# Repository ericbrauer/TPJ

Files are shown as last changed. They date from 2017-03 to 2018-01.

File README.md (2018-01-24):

# TPJ
Final Project for ECT @ Seneca. "Project Skylight"

# PROJECT SKYLIGHT
Eric Brauer 

## Executive Summary
Project Skylight is an Internet-connected light that simulates daylight cycles. It’s meant for
use in places where there are no external windows, and it can be used to get a quick visual
reference for the time of day. Project skylight is composed of a small microcontroller with wifi
capabilities, and 16 RGB LEDs. The device is meant to run with very little set-up, but a
web-based user interface can be used for further configuration. In the report, the operation
and specifications of Project Skylight are covered in more detail.

## Functional Features
The product requirements, as envisioned, are as follows:
- Project Skylight (PS) asks for WiFi credentials, and connects to a WiFi router.
- PS serves a webpage which is used to configure the device and to provide the user’s
city of residence.
- PS uses the OpenWeatherMap API to get the time of dawn and dusk. The device
also uses an NTP server to synchronise the current time.
- PS changes the colour and brightness of LEDs based on current time in reference to
sunrise and sunset times.
- PS monitors a potentiometer, which will be used to dim or turn off the LED light.
- Further configuration is possible from the web interface. This includes setting manual
daylight times.

## Product Specifications
- Powered from micro USB port
- Operates at nominal indoor temperatures, not for outdoor use
- Luminosity of around 200 - 400 Lumens
- WiFi range 20m
- Current consumption no higher than 1.5A

## Theory of Operation
### Power Concerns
The ESP-12f requires a typical voltage of 3.3 Volts. The Neopixel array require a voltage of 4
to 7 Volts. Thus a voltage regulation stage is required. USB provides 5 Volts, and this power
is used for the Neopixels. Power for the ESP-12f is supplied by an LD1117.

Power consumption is based heavily on several factors: transmission and reception by the
WiFi module on the ESP-12f, signal strength of the same, and brightness levels of the
Neopixels. If a single Neopixel is set to white with maximum brightness, then each of its
three RGB LEDs requires 20 mA. There is never a situation when the Skylight is generating
this state, however. Full brightness of the daytime SkyState would represent the maximum
current consumption.

4 LEDs displaying white = 60mA * 4 240mA

12 LEDs displaying cyan = 40mA * 12 480mA

Total Current for Neopixels: **720mA**

In addition, the ESP-12f requires a maximum of 100mA. Meaning that a USB adapter rated
at 1A should be sufficient for proper function and also provide a buffer of almost 20%.

### Initial State / Connectivity
The ESP-12f is a popular IC among the maker community, and much work has been done to
implement a thorough Arduino library which exposes much of the connectivity capability of
the chip. The Skylight in particular makes use of several libraries to implement the initial
Access Point state (used to enter WiFi credentials), to communicate to OpenWeatherMap,
and to serve a web-based user interface.

**ESP8266WiFi** exposes functions for connecting to a WiFi access point and communicating
over TCP/IP.

**ESP8266WebServer** allows to ESP to also act as a web server, and serve HTTP code to
clients.

**ESP8266mDNS** provides a ‘micro DNS’ server which will associate a URL with whatever IP
address is assigned to the ESP’s web server.

**WifiManager** checks flash for a WiFi SSID and password that was previously used to
connect. If these don’t exist, WifiManager will set the ESP-12 to station mode with an SSID
set in software. The user can connect to this access point, and then navigate to the url
specified by the micro-DNS server. From this webpage, the user has the option to scan for
available access points, and then enter a password to connect to this access point. From
this point, the ESP exits station mode and attempts to connect to the access point as a
client. If it is successful, these credentials will be saved in flash memory to be used on
startup.

### The Web Interface
The ESP handles web requests directed at the url created by the micro DNS server. On the
Skylight, the url is skylight.local. The main interface is located at the root. Other webpages
are used to acknowledge user requests, and exist at /submit, /demo and /reset. All other
requests will result in a HTTP code of 404.
A typical user request is to manually change the time at which a sunset event occurs. The
time desired is typed into text boxes, and the ‘save’ button is pressed. Information inside the
text boxes is saved as arguments. The arguments are validated first. The arguments are
checked to ensure that they are numerical and in a proper 12-hour time format. A bad
request will result in a ‘bad request’ message and a link back to the root page. A good
request will be accepted. Finally, the browser will navigate to skylight.local/submit, where the
user is notified that the alarm has been set.

### Adafruit NeoPixel Array
Neopixels are addressable RGB LEDs. Control circuitry, LEDs, and internal oscillators are all
included in one package. Data can be received from a microcontroller at speeds of 800kbps,
and outputted to the next neopixel. This allows an array of neopixels to be controlled from
one data pin.
Each neopixel requires 24bits of information. The first neopixel uses 24 bits to set the values
of discrete red, green and blue LEDs. Each of these LEDs takes a PWM 8-bit signal to set its
intensity, resulting in 255 possible states. Once the state of neopixel has been set,
subsequent data is amplified and sent through a ‘Data Out’ line to program the next
neopixel. The advantage of neopixels is their flexibility, but larger arrays will require far more
memory and processing than some microcontrollers can provide. Since the Skylight uses
only 16 neopixels, performance requirements are relatively light.9
Adafruit provides an Arduino Library for communicating with the Neopixel array. The
Neopixels are powered from a 5V VCC line and the data line is connected to the ESP’s
GPIO pin 14.
### Brightness Control
A potentiometer is connected to the ESP-12’s single Analog-to-Digital converter. A standard
Arduino library function is used to convert this number to a 10-bit value, which is then to an
8-bit value using bit shift. The 8-bit value is used as an argument for the setBrightness
function which is part of the Adafruit Neopixel library. Using the ADC with interrupts proved
to be problematic, and so the ADC is polled in loop() and if its value changes, the
setBrightness function is called. The potentiometer is connected to the ADC pin identified as
0.
### Setting dusk_time and dawn_time From OpenWeatherMap.org
OpenWeatherMap provides an API that can be used for free with registration for a smaller
number of requests. For the Skylight prototype, this is sufficient. Documentation for the API
is located at  [OpenWeatherMap](http://openweathermap.org/current). The API can be used with several different
formats of location data; for simplicity’s sake a GET request is used encoded with the city
and country code are used along with an API key.
The HTTP response is in a JSON format. First, the HTTP header of the response is
discarded. Then ArduinoJson library is used to parse the response. Most information is
related to weather conditions and is not used. The sunrise and sunset times are sent in
epoch time based on UTC. In order to set this to local time, a timezone offset is added to
these times and the result is stored in memory.
### Using NTP to Sync Local Time
NTPClient is another library used to communicate with NTP servers. This is used with
TimeLib to set the ESP’s time. A timezone offset is required by the library.
### State Machine
Assuming that NTP and GET Requests have succeeded, the Skylight will compare current
time with the next scheduled event. Once current time is within forty minutes of a sunrise or
sunset, the Skylight enters a DUSK or DAWN event. Both events are identical, but DUSK
occurs in reverse order.
There are three parts to a transition, and each takes 20 minutes. Two of the parts of the
transition occur before the event time, and one occurs after. Each part of the transition is
handled by a function, and each function takes as an argument an 8-bit number.

`SkyState1(0-255) SkyState2(0-255) SkyState3(0-255)`

Duration: 1200 seconds Duration: 1200 seconds Duration: 1200 seconds
In the case of DAWN, the actual sunrise_time is the time between SkyState2 and SkyState3.
In order to set the argument for each SkyState function, a simple equation derived from the
Radiometric Equation is used.

`y = (x - 2400) / (-3600 / 765)`

Where x is equal to seconds until event and y is equal to the skyState argument.
What this means is that approximately every 7 seconds, SkyState functions will increment
the levels of the Neopixel LEDs which results in a simulated dawn or dusk event. Once the
current time is over twenty minutes past the last event, the state machine will return to a
state where it decides if it is waiting for dawn or waiting for dusk. If both dawn and dusk
events are earlier than the current time, the state machine will attempt to request new times
from OpenWeatherMap.

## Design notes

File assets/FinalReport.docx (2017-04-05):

# Project Skylight

Project Report

Eric Brauer

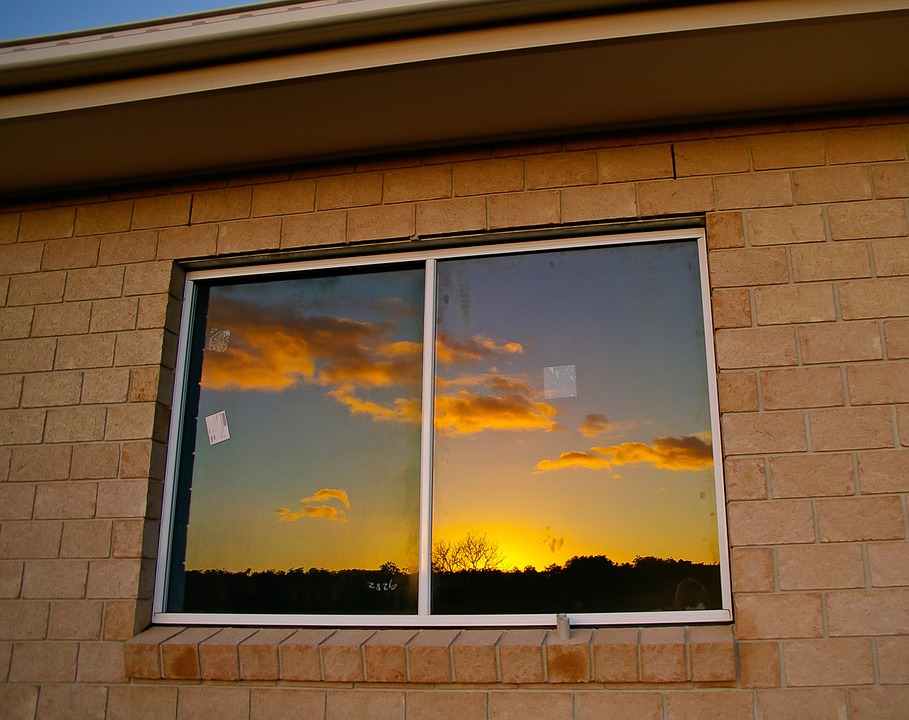
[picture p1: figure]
window reflection sky sunset ...

Subject: Technology Project - TPJ655

Program: Computer Engineering Technology

Instructor: B. Shefler, rm. A4022, ext. 26429

Date: 4/4/2017

SENECA COLLEGE OF APPLIED ARTS AND TECHNOLOGY

School of Electronics and Mechanical Engineering Technology

1750 Finch Ave East, Toronto, Ontario, M2J 2X5. Tel. 416-491-5050 Fax 416-490-9839

www.senecacollege.ca

Executive Summary 2

Introduction 3

Functional Features 3

Product Specifications 3

Operating Instructions 3

Design 4

Hardware Block Diagram 4

Software Flow Chart 5

Description of Components 6

Graphical User Interface Mockups 7

Theory of Operation 7

Maintenance Requirements 10

Conclusion 10

Further Steps 11

Appendix 12

Schematic 12

Bill Of Materials 13

Datasheets 13

Contact Information 13

On the CD: 14

## Executive Summary

Project Skylight is an Internet-connected light that simulates daylight cycles. It’s meant for use in places where there are no external windows, and it can be used to get a quick visual reference for the time of day. Project skylight is composed of a small microcontroller with wifi capabilities, and 16 RGB LEDs. The device is meant to run with very little set-up, but a web-based user interface can be used for further configuration. In the report, the operation and specifications of Project Skylight are covered in more detail.

## Introduction

In Toronto and in many densely-populated areas, people often and work in rooms without exterior windows. With no visual reference to the time of day, it can be easy to lose track of time: whether it’s daytime, evening, or night. This leads to feelings of disorientation and can exacerbate sleep disturbances.

Project skylight is meant to address this problem. The device being proposed is an Internet-connected light that simulates the time of day. The time of day is simulated with an appropriate colour and brightness of light. Daytime, nighttime, and transitional periods ie. dawn and dusk would have different characteristics which would give people the same quick visual reference that one usually gets by glancing out the window.

## Functional Features

The product requirements, as envisioned, are as follows:

- Project Skylight (PS) asks for WiFi credentials, and connects to a WiFi router.
- PS serves a webpage which is used to configure the device and to provide the user’s city of residence.
- PS uses the OpenWeatherMap API to get the time of dawn and dusk. The device also uses an NTP server to synchronise the current time.
- PS changes the colour and brightness of LEDs based on current time in reference to sunrise and sunset times.
- PS monitors a potentiometer, which will be used to dim or turn off the LED light.
- Further configuration is possible from the web interface. This includes setting manual daylight times.

## Product Specifications

- Powered from micro USB port
- Operates at nominal indoor temperatures, not for outdoor use
- Luminosity of around 200 - 400 Lumens
- WiFi range 20m
- Current consumption no higher than 1.5A

## Operating Instructions

Before proceeding, please observe the following safety instructions:

For indoor use only. Keep away from water or heat sources. Use only power adapters approved by the CSA.

Initial Setup:

- Project Skylight can be used with any micro-USB power adapter that supplies 5V. It should also be able to supply 1A. Plug the Skylight into the wall, and hang it or place it wherever you like.
- On startup, the light will flash yellow. This means that the skylight was unable to detect a wifi station in memory, and is in station mode so that wifi information can be entered.
- Use a smartphone or laptop to connect to the Access Point called ‘SKYLIGHT.’ Once connected, use the browser to go to skylight.local.
- Select your home router, and enter the password. The skylight will now attempt to connect to the internet. If it is successful, you should see it simulate the time of day. If there is a problem, the light will blink red. Please check your wifi information again, or contact customer support.

Changing brightness:

- Use the dial or adjust desired brightness. These settings will be remembered until you change them. If the skylight doesn’t seem to be responding, check first that the light hasn’t been turned off.

Changing transition times:

- If you wish to change the time at which sunrise or sunset are initiated, use a device connected to your home router. Open a browser window and go to skylight.local.
- Set a time for sunrise or sunset, and press the ‘save’ button. If the time entered is valid, the skylight will transition 30 minutes before the specified time, and the transition will be completed 30 minutes after. Manual times do not repeat. After the specified time, the skylight will revert to simulating the actual time of day.

## Design

### Hardware Block Diagram

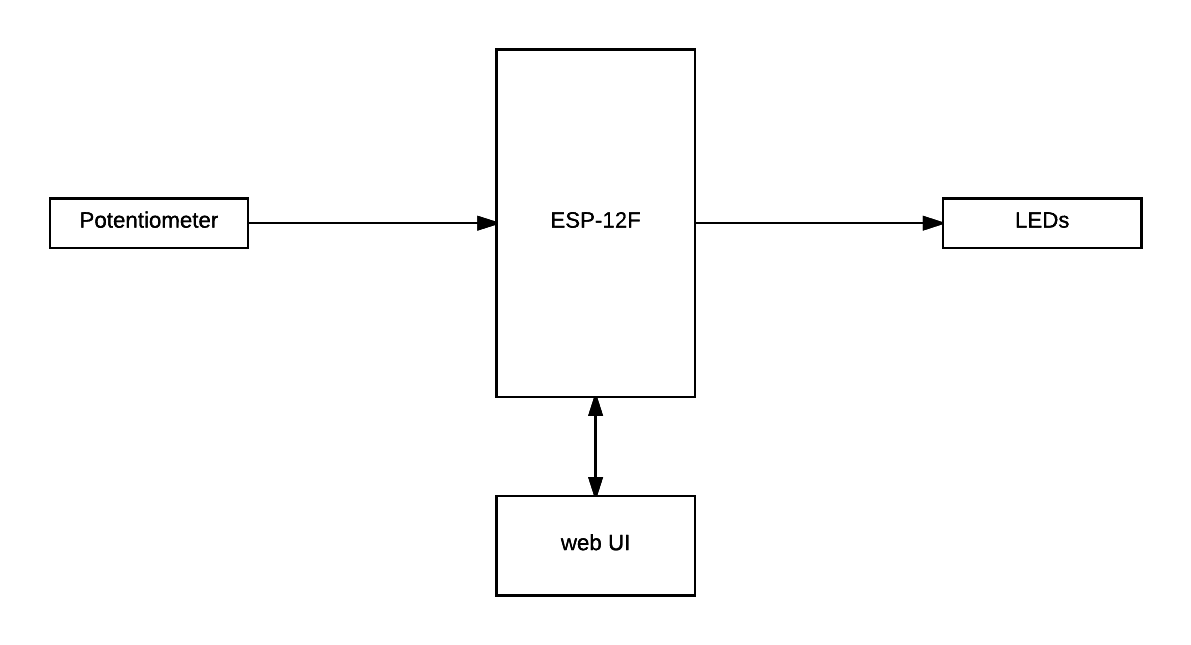
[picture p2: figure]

### Software Flow Chart

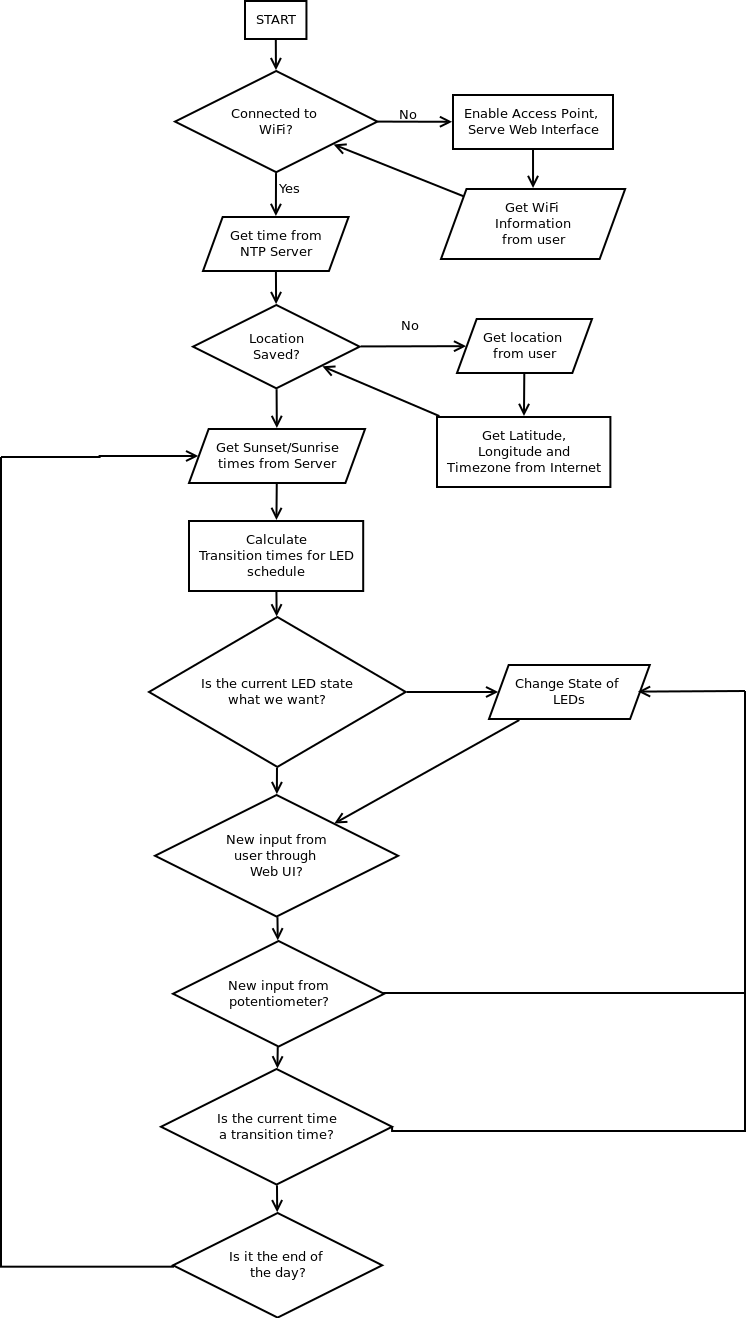
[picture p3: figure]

### Description of Components

# | Component Name | Specifications

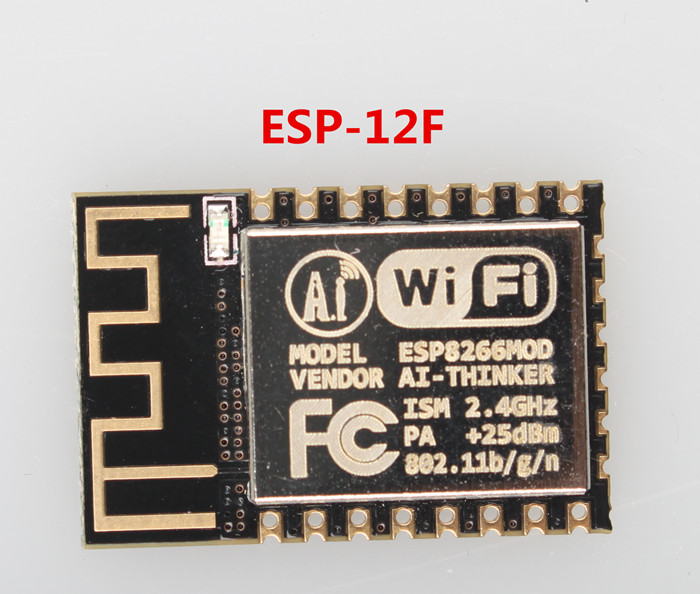
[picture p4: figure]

1 | Espressif ESP-12f | - Operating Voltage: 3.0~3.6V - Operating Current Average value: 80mA - SDIO 2.0, (H) SPI, UART, I2C, I2S, IRDA, PWM, GPIO - 802.11 b/g/n - Integrated low power 32-bit MCU, 80 MHz clock speed - 36 kB RAM, 2 MB flash

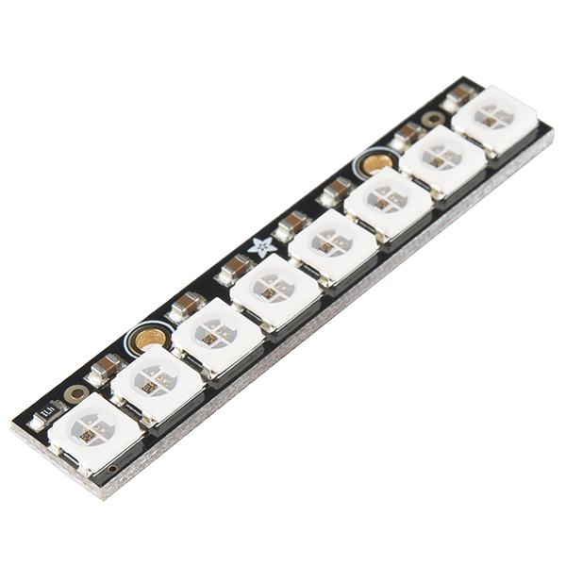
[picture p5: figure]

2 | Adafruit Neopixel Strip | - Provides 8 WS2812b Addressable RGB LEDs - Voltage VCC: +6.0~+7.0V - Operating current: 60mA - 256 brightness levels per colour

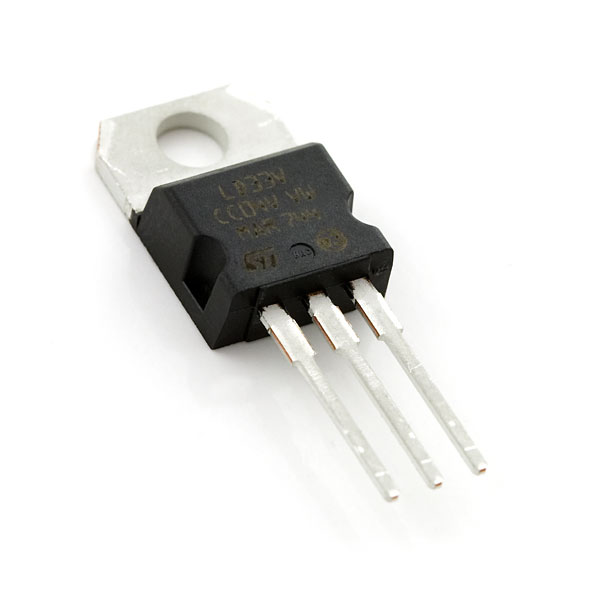
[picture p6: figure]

3 | LD1117V33 Voltage Regulator | - Output Voltage: 3.3V - Output Current: 800mA - Dropout Voltage: 1V

### Graphical User Interface Mockups

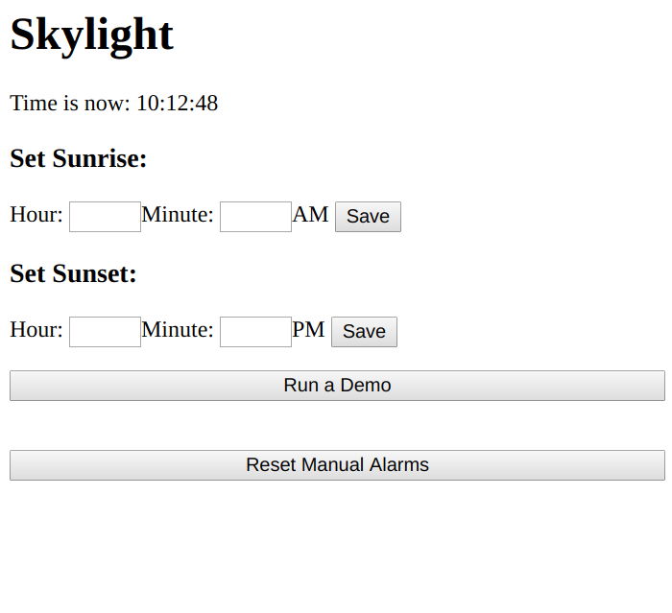
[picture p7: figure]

### Theory of Operation

Power Concerns

The ESP-12f requires a typical voltage of 3.3 Volts. The Neopixel array require a voltage of 4 - 7 Volts. Thus a voltage regulation stage is required. USB provides 5 Volts, and this power is used for the Neopixels. Power for the ESP-12f is supplied by an LD1117.

Power consumption is based heavily on several factors: transmission and reception by the WiFi module on the ESP-12f, signal strength of the same, and brightness levels of the Neopixels. If a single Neopixel is set to white with maximum brightness, then each of its three RGB LEDs requires 20 mA. There is never a situation when the Skylight is generating this state, however. Full brightness of the daytime SkyState would represent the maximum current consumption.

4 LEDs displaying white = 60mA * 4 | 240mA
12 LEDs displaying cyan = 40mA * 12 | 480mA
Total Current for Neopixels: | 720mA

In addition, the ESP-12f requires a maximum of 100mA. Meaning that a USB adapter rated at 1A should be sufficient for proper function and also provide a buffer of almost 20%.

Initial State / Connectivity

The ESP-12f is a popular IC among the maker community, and much work has been done to implement a thorough Arduino library which exposes much of the connectivity capability of the chip. The Skylight in particular makes use of several libraries to implement the initial Access Point state (used to enter WiFi credentials), to communicate to OpenWeatherMap, and to serve a web-based user interface.

ESP8266WiFi exposes functions for connecting to a WiFi access point and communicating over TCP/IP.

ESP8266WebServer allows to ESP to also act as a web server, and serve HTTP code to clients.

ESP8266mDNS provides a ‘micro DNS’ server which will associate a URL with whatever IP address is assigned to the ESP’s web server.

WifiManager checks flash for a WiFi SSID and password that was previously used to connect. If these don’t exist, WifiManager will set the ESP-12 to station mode with an SSID set in software. The user can connect to this access point, and then navigate to the url specified by the micro-DNS server. From this webpage, the user has the option to scan for available access points, and then enter a password to connect to this access point. From this point, the ESP exits station mode and attempts to connect to the access point as a client. If it is successful, these credentials will be saved in flash memory to be used on startup.

The Web Interface

The ESP handles web requests directed at the url created by the micro DNS server. On the Skylight, the url is skylight.local. The main interface is located at the root. Other webpages are used to acknowledge user requests, and exist at /submit, /demo and /reset. All other requests will result in a HTTP code of 404.

A typical user request is to manually change the time at which a sunset event occurs. The time desired is typed into text boxes, and the ‘save’ button is pressed. Information inside the text boxes is saved as arguments. The arguments are validated first. The arguments are checked to ensure that they are numerical and in a proper 12-hour time format. A bad request will result in a ‘bad request’ message and a link back to the root page. A good request will be accepted. Finally, the browser will navigate to skylight.local/submit, where the user is notified that the alarm has been set.

Adafruit NeoPixel Array

Neopixels are addressable RGB LEDs. Control circuitry, LEDs, and internal oscillators are all included in one package. Data can be received from a microcontroller at speeds of 800kbps, and outputted to the next neopixel. This allows an array of neopixels to be controlled from one data pin.

Each neopixel requires 24bits of information. The first neopixel uses 24 bits to set the values of discrete red, green and blue LEDs. Each of these LEDs takes a PWM 8-bit signal to set its intensity, resulting in 255 possible states. Once the state of neopixel has been set, subsequent data is amplified and sent through a ‘Data Out’ line to program the next neopixel. The advantage of neopixels is their flexibility, but larger arrays will require far more memory and processing than some microcontrollers can provide. Since the Skylight uses only 16 neopixels, performance requirements are relatively light.

Adafruit provides an Arduino Library for communicating with the Neopixel array. The Neopixels are powered from a 5V VCC line and the data line is connected to the ESP’s GPIO pin 14.

Brightness Control

A potentiometer is connected to the ESP-12’s single Analog-to-Digital converter. A standard Arduino library function is used to convert this number to a 10-bit value, which is then to an 8-bit value using bit shift. The 8-bit value is used as an argument for the setBrightness function which is part of the Adafruit Neopixel library. Using the ADC with interrupts proved to be problematic, and so the ADC is polled in loop() and if its value changes, the setBrightness function is called. The potentiometer is connected to the ADC pin identified as 0.

Setting dusk_time and dawn_time From OpenWeatherMap.org

OpenWeatherMap provides an API that can be used for free with registration for a smaller number of requests. For the Skylight prototype, this is sufficient. Documentation for the API is located at http://openweathermap.org/current. The API can be used with several different formats of location data; for simplicity’s sake a GET request is used encoded with the city and country code are used along with an API key.

The HTTP response is in a JSON format. First, the HTTP header of the response is discarded. Then ArduinoJson library is used to parse the response. Most information is related to weather conditions and is not used. The sunrise and sunset times are sent in epoch time based on UTC. In order to set this to local time, a timezone offset is added to these times and the result is stored in memory.

Using NTP to Sync Local Time

NTPClient is another library used to communicate with NTP servers. This is used with TimeLib to set the ESP’s time. A timezone offset is required by the library.

State Machine

Assuming that NTP and GET Requests have succeeded, the Skylight will compare current time with the next scheduled event. Once current time is within forty minutes of a sunrise or sunset, the Skylight enters a DUSK or DAWN event. Both events are identical, but DUSK occurs in reverse order.

There are three parts to a transition, and each takes 20 minutes. Two of the parts of the transition occur before the event time, and one occurs after. Each part of the transition is handled by a function, and each function takes as an argument an 8-bit number.

SkyState1(0-255) | SkyState2(0-255) | SkyState3(0-255)
Duration: 1200 seconds | Duration: 1200 seconds | Duration: 1200 seconds

In the case of DAWN, the actual sunrise_time is the time between SkyState2 and SkyState3. In order to set the argument for each SkyState function, a simple equation derived from the Radiometric Equation is used.

y = (x - 2400) / (-3600 / 765)

Where x is equal to seconds until event and y is equal to the skyState argument.

What this means is that approximately every 7 seconds, SkyState functions will increment the levels of the Neopixel LEDs which results in a simulated dawn or dusk event. Once the current time is over twenty minutes past the last event, the state machine will return to a state where it decides if it is waiting for dawn or waiting for dusk. If both dawn and dusk events are earlier than the current time, the state machine will attempt to request new times from OpenWeatherMap.

### Maintenance Requirements

The skylight is designed to run without any interference whatsoever. The LEDs used should last for years, and there should be few if any problems. The exception to this relates to internet connectivity.

If the skylight flashes red, there could be problems connecting to the server required for time synchronisation.

- Unplug the skylight, then plug it back in. This should cause the system to reboot, and to check connectivity. If the device flashes red after a reboot, check that your home router is connected to the internet.
- It is possible that a software update will be required to ensure proper function. To initiate an OTA update check, reboot the skylight. Note: This is not yet implemented.

If the device seems to be responsive but there are no lights, first check that the brightness dial is not turned off. If lights fail to engage, check that the power adapter is not faulty.

## Conclusion

Project Skylight fulfills the features as they were laid at the outset of the project. The device syncs with NTP, performs GET requests, servers a web UI and does a good job of simulating time of day. In addition, it is easy to set up and runs well without interference. The cost of materials for this project was under $50 and could easily be dropped down, possibly under $20 on a larger scale.

The question of what would need to change in order for this to be mass produced is an interesting one. The price of materials would obviously drop significantly, but several new challenges would arise.

- Security / Privacy: The Skylight is quite secure by default. It does not require any personal information to be logged apart from WiFi credentials, and the web interface is only accessible to people who are connected to the same WiFi. While the information sent to OpenWeatherMap is not protected, it only includes the user’s city of residence and so is not sensitive. There is one possible vector of attack: during initial setup, the Skylight sets up a station and gets the user’s wifi credentials. This station could easily be spoofed and the attacker would gain the user’s WiFi credentials. If this were to be commercial product, this and other possible vectors of attack would need to be addressed.
- API: The Skylight uses a free API from OpenWeatherMap, but this wouldn’t be available to a commercial product without service fees. It might make more sense for a business producing Skylights to set up their own server for requests. Of course, if the business went bankrupt then shutting down the server would make the Skylight useless. Such is the reality of IoT devices.
- Time / Location: The difficulties of timezones and locations are myriad and would present some challenges for a commercial product. In the present prototype, location and timezone offset are hard-coded. A commercial product would need to get this information from the user, or otherwise get it from the device. Inputting the city of residence from the user is not a good solution, since it excluding people living outside of cities. In addition, if there are multiple cities with the same name, this would also cause a problem. The best solution would be city ID codes, but users don’t know these. A separate API call would be required: users would enter their city, be presented with a list of possible cities, and then the city ID code of their selection would be used for all future requests. Timezones require an additional request, since timezone information is not part of OpenWeatherMap’s API. These challenges would easily be addressed by a custom server and API.
- Enclosure: The Skylight includes an array of Neopixels placed behind a diffusion panel held in a 4” x 6” picture frame. This solution is unwieldy, and is different from the proposed enclosure, which was envisioned to hang from a wall. Placing the LEDs closer to the frame didn’t produce the desired effect. A more appropriate enclosure would need to be developed for a viable commercial product.

### Further Steps

The following features were not defined as requirements, but would be further enhancements that could be implemented:

- Themes: Instead of time of day, the user could select themes from the user interface. Some possibles themes include: fireplace, aquarium, lava lamp, and possibly others.
- Light timers: People often buy light timers to protect their homes when they are on vacation. The timers turn on lights at set times, in order to fool potential burglars. PS would have the same functionality.
- Brightness monitor: By including a brightness monitor, the PS could detect when the user has turned off their other bedroom lights. From this information the PS could monitor how late the user is staying up past ‘sunset.’ This information could be uploaded to a database, and made accessible to the user for perusal.
- Integration with MQTT notifications: MQTT is a technology where IoT devices can generate push notifications to users’ mobile devices. The PS could be used to generate gentle light notifications: possibly blink an LED to get the user’s attention.

# Appendix

### Schematic

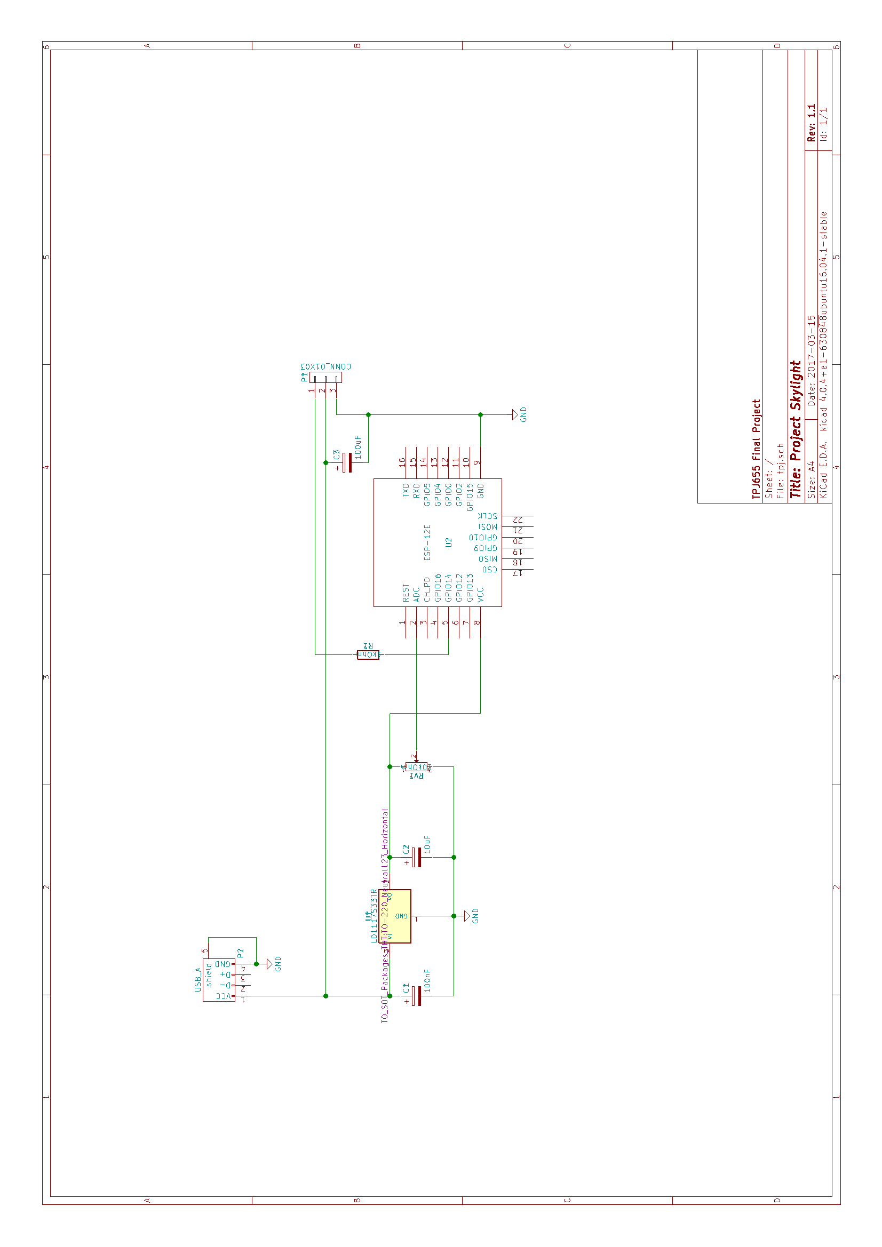
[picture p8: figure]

### Bill Of Materials

Part # | Model | Designation | Description | Source | Cost per Unit | Quantity | Subtotal
1 | ESP-12F | U2 | WiFi/MCU | Ebay | $2.45 | 1 | $2.45
2 | NeoPixel Strip | N/A | LEDs | Creatron | $6.95 | 2 | $13.90
3. | 10kOhm log | RV1 | Potentiometer | Home Hardware | $1.00 | 1 | $1.00
4. | USB B female port | P2 | 9V DC Jack / USB | Creatron | $2.35 | 1 | $2.35
5. | LD-1117 | U1 | Regulator: 3.3V out | Creatron | $2.45 | 1 | $2.45
6. | 10uF, 100uF Electrolytic Caps. | C2, C3 | Capacitor | Home Hardware | $0.45 | 2 | $0.90
7. | 0.1uF ceramic Cap. | C1 | Capacitor | Creatron | $0.80 | 1 | $0.80
8. | JST connector | P1 | Cable for LEDs | Creatron | $1.18 | 1 | $1.18
9. | PCB | N/A | PCB | Oshpark | $7.45 | 1 | $7.45
10.. | Mylar sheet | N/A | Diffusion panel | TBD | $5.00 | 1 | $5.00
11. | 4” x 6” | N/A | Picture Frame | Dollarama | $2.00 | 1 | $2.00
Subtotal | | | | | | | $39.48
Total with HST | | | | | | | $44.61

### Datasheets

ESP-12F: https://www.elecrow.com/download/ESP-12F.pdf

WS2812B: https://cdn-shop.adafruit.com/datasheets/WS2812B.pdf

LD1117V33: https://www.sparkfun.com/datasheets/Components/LD1117V33.pdf

### Contact Information

Eric Brauer 647-235-6609 eric.m.brauer@gmail.com

### On the CD:

The CD includes the following:

- This file (docx, pdf)
- Project Proposal (docx, pdf)
- Presentation slides (pptx, pdf)
- Gantt chart (mpp)
- Schematic (pdf)
- Source code (main.cpp)
- Platformio.ini (contains links to third-party libraries)
- Datasheets for ESP-12f and WS2812b
- Project folder (includes all the above)

Files will also be available from:

https://github.com/ericbrauer/TPJ

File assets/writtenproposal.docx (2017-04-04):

# Project Skylight

Project Proposal

Eric Brauer

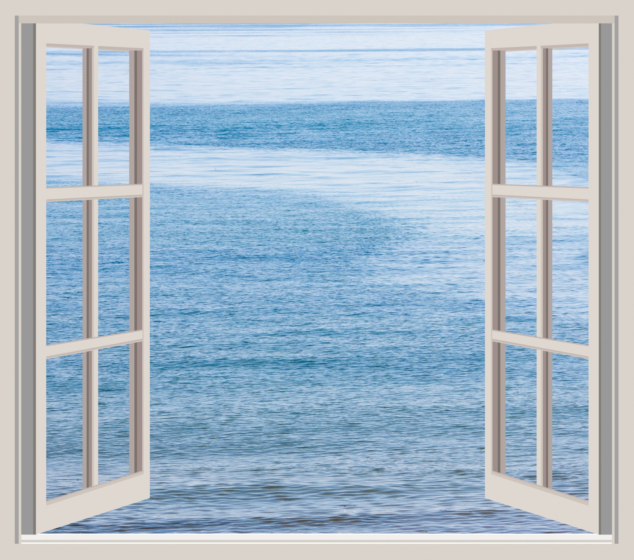
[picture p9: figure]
Ocean Through Window Frame

Subject: Technology Project - TPJ655

Program: Computer Engineering Technology

Instructor: B. Shefler, rm. A4022, ext. 26429

Date: 29/1/2017

SENECA COLLEGE OF APPLIED ARTS AND TECHNOLOGY

School of Electronics and Mechanical Engineering Technology

1750 Finch Ave East, Toronto, Ontario, M2J 2X5. Tel. 416-491-5050 Fax 416-490-9839

www.senecacollege.ca

Introduction 2

Product Requirements 2

Product Specifications 3

Some pertinent specifications of the ESP-12F: 3

Some Pertinent Specifications of Proposed NeoPixel Strip: 3

Overall Product Specifications: 4

Hardware Block Diagram 4

Project Plan 4

Software Flow Chart 5

Bill Of Materials 6

Contact Information 6

### Introduction

In Toronto and in many densely-populated areas, people often and work in rooms without exterior windows. With no visual reference to the time of day, it can be easy to lose track of time: whether it’s daytime, evening, or night. This leads to feelings of disorientation and can exacerbate sleep disturbances.

Project skylight is meant to address this problem. The device being proposed is an Internet-connected light that simulates the time of day. The time of day is simulated with an appropriate colour and brightness of light. Daytime, nighttime, and transitional periods ie. dawn and dusk would have different characteristics which would give people the same quick visual reference that one usually gets by glancing out the window.

This is a viable project because the constituent parts are relatively straightforward, but the functionality could easily be expanded upon. There are three major aspects to the project: internet connectivity, a web-based user interface, and lights with controllable colour and brightness levels. In addition, the device would be easy to set up for a layperson. The information required from a user would be limited: first, wifi credentials, then location. Beyond that, the device would be able to function independent of the user, and the hardware inputs would be limited: simply a dial for adjusting brightness. The effect would be pleasing without further input. The cost for components, I believe, would be reasonable. The microcontroller can be bought for around $2 CAD, and the addressable LEDs can be bought for around $1 CAD each. The rest of the components, ie. resistors, potentiometer, USB port, PCB, would not add up to much beyond this.

My strategic objective, first and foremost, is to become familiar with a particular component: the ESP-12F. The ESP-12F is a wifi module that also integrates an ESP8266, which is an arduino-compatible microcontroller. The ESP-12F is becoming popular as the foundation of many Internet of Things (IoT) devices, and it would benefit me greatly to gain some experience programming this device.

In addition, I would also like to indicate that my interest in this particular project is a personal one. When I sleep in a bedroom with no external windows, I often wake up feeling very disoriented, waking up as I am in the same darkness that I went to bed in. I have often thought about how something like ‘project skylight’ would be beneficial.

### Product Requirements

The product requirements, as envisioned, are as follows:

- Project Skylight (PS) will ask for WiFi credentials, and connect to a WiFi router.
- PS will synchronise with an NTP server.
- PS will ask for the user’s location, and store this information.
- PS will use the user-inputted location to determine time zone, and latitude/longitude. The easiest way to do this would be to communicate with a web server, post the user input, and get timezone/latitude and longitude information.
- PS will set the timezone, and post the latitude/longitude information to a web server. The web server will return times for sunrise and sunset.
- PS will change the colour and brightness of LEDs based on current time in reference to sunrise and sunset times.
- PS will monitor a potentiometer, which will be used to dim or turn off the LED light.
- PS will also serve a web interface from which the user can further control the device.

The following features are not defined as requirements, but are further enhancements that would be implemented if time allows:

- Themes: Instead of time of day, the user could select themes from the user interface. Some possibles themes include: fireplace, aquarium, lava lamp, and possibly others.
- Alarms: Instead of simulating actual time of day, the device could be set to simulate a sunrise at a specific time. This would be a subtle, light-based alarm clock.
- Light timers: People often buy light timers to protect their homes when they are on vacation. The timers turn on lights at set times, in order to fool potential burglars. PS would have the same functionality.
- Brightness monitor: By including a brightness monitor, the PS could detect when the user has turned off their other bedroom lights. From this information the PS could monitor how late the user is staying up past ‘sunset.’ This information could be uploaded to a database, and made accessible to the user for perusal.
- Go To Sleep: There are applications available for your computer that tint the display based on time of day. The theory behind these applications is that blue light from an LED can ‘fool’ the body’s circadian rhythms into staying awake longer. In response, the application will tint the monitor’s display to become warmer, ie. with less blue. The PS could emulate this behaviour.

### Product Specifications

#### Some pertinent specifications of the ESP-12F:

- Operating Voltage: 3.0~3.6V
- Operating Current Average value: 80mA
- SDIO 2.0, (H) SPI, UART, I2C, I2S, IRDA, PWM, GPIO
- 802.11 b/g/n
- Integrated low power 32-bit MCU, 80 MHz clock speed
- 36 kB RAM, 2 MB flash
- Integrated 10-bit ADC

Datasheet here: https://www.elecrow.com/download/ESP-12F.pdf

#### Some Pertinent Specifications of Proposed NeoPixel Strip:

- Integrated RGB LEDs
- Voltage VCC: +6.0~+7.0V
- Operating current: 60mA
- 256 brightness levels per colour

Datasheet here: https://cdn-shop.adafruit.com/datasheets/WS2812B.pdf

#### Overall Product Specifications:

- Powered from either USB port, or standard 9V DC power adapter (TBD)
- Operates at nominal indoor temperatures, not for outdoor use
- Luminosity of around 200 - 400 Lumens
- WiFi range of around 20m
- Current consumption no higher than 1.5A

### Hardware Block Diagram


### Project Plan

1. Procure development board, and potential LEDs
2. Evaluate parts, ensure that they fulfill requirements of the project
3. Program proof-of-concept functions, ensure that the MCU can perform the required functions, become familiar with Arduino libraries
4. Integrate proof-of-concept modules into a single program that fulfills basic requirements
5. Build prototype of hardware on breadboard, ensure proper function of the hardware and software
6. Evaluate hardware design based on heat, power, efficiency, visual design and any other factors
7. Design a PCB and order it, or print it at the college
8. Procure materials for finished product
9. Make changes to the code to improve performance, or to enhance features
10. Final assembly and demonstration

### Software Flow Chart


### Bill Of Materials

Component | Name | Source | Cost
WiFi/MCU | ESP-12F | Ebay | $2.45
LEDs | NeoPixel Strip | Creatron | $6.95 x 2
Potentiometer | TBD | TBD | $~1.50
9V DC Jack / USB | TBD | TBD | $~2.00
Regulator: 3.3V out | LD-1117 | Creatron | $1.75
PCB | N/A | Oshpark/Seneca | $0~20[^1]
Diffusion panel[^2] | N/A | TBD | $~20
Total | | | $24 ~ $47[^3]

### Contact Information

Eric Brauer 647-235-6609 eric.m.brauer@gmail.com

[^1] Oshpark charges $5.00 per square inch. This price assumes a board of 2 square inches, plus shipping. I’m not sure how it would work to get Seneca to print a PCB, it will require investigation.
[^2] This may not be required, but will be added if it increases the visual appeal. Most likely would be a piece of plexiglass, rubbed with fine sandpaper in order to ‘bleed’ the light of the LEDs together.
[^3] Includes HST.

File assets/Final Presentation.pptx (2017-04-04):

## Project Skylight

A Smartlamp Providing Clarity

Eric Brauer
eric.m.brauer@gmail.com

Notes: Hell and welcome to my presentation. My name is Eric Brauer and today I would like to demonstrate my TPJ project and talk a little about what it can offer.

## Agenda:

- What is it?
- Why?
- Demo
- Features
- Technical Overview
- Where to go from here

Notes: And just to talk about how this presentation is going to be structured: I will start by explaining what Project Skylight is and what it was meant to accomplish. After that I will walk you through the process of setting it up, and then into more detail about how it works.

## Project Skylight is an Internet-Connected Lamp.

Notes: Basically, Project Skylight is an internet-connected lamp that simulates the time of day. This being Toronto, it goes without saying that the cost of living is high, and a lot of people find themselves living in basement apartments.

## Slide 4

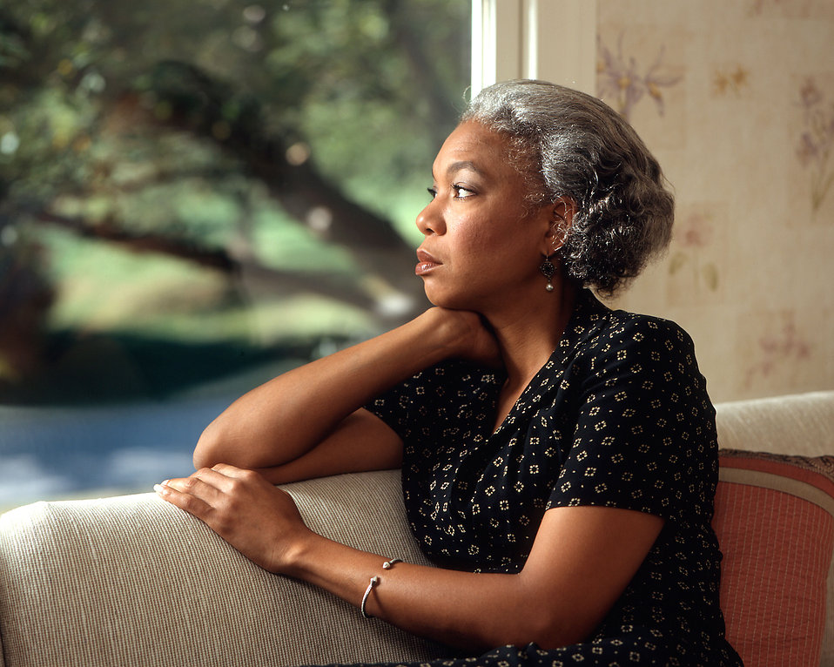
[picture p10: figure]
... woman looking out a window ...

A view of the outside world.

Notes: An exterior window can quickly give you a visual reference to the time of day, and I think it’s something that we take for granted. I know that whenever I’ve been in rooms without external windows, it can be a disorienting experience. If you are trying to maintain a natural sleeping pattern, It can be hard to wake up without daylight, and when you do so it can often be disorienting and uncomfortable.

## Addressing the Problem of Disorientation.

Simple, and Cost-efficient.

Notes: I think that having a visual reference to the outside world is something that’s very primal and natural for us humans. And that is what the Skylight is meant to provide: a simulated visual reference to the time of day. It’s meant to brighten a room in the morning, and let people know when it’s getting dark out. In addition, I thought about the people who might be interested in such a product. They aren’t necessarily tech enthusiasts, and don’t necessarily have a huge amount of disposable income. In thinking about this demographic, I formulated some other goals for the project: I wanted it to be simple to set up, and mostly autonomous, and under 50 dollars. This is meant to be a solution for everyday people, not just tech enthusiasts.

## Demonstration:

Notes: And so, to demonstrate that, I would like to now go through the process of setting up the Skylight for the first time. The Skylight takes any standard micro-USB adapter for power. The first time it starts up, it will need to get connected to a wifi Access Point. Since it doesn’t know where to connect, it will start in Station mode. I will use my laptop to connect to ‘SKYLIGHT’, where I can enter my credentials.

## Demonstration:

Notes: I’m using my phone as a hotspot for this demonstration. Once I have entered the correct credentials, the Skylight will download time of day information and get the correct time. And it should understand that we are in the middle of the day, and set the lights accordingly.

## Demonstration:

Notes: Now that we’ve connected to an Access Point, the skylight will remember the credentials and attempt to connect to it on startup. And now to Control the skylight, we can connect to the same access point as the skylight, and navigate to ‘skylight.local.’

## The GUI.

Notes: And now we have some options to control the Skylight. These are pretty basic, as I wanted to limit the scope of the project as much as possible. But I can easily show you what a dawn or dusk transition looks like in fast forward. (Run the demo). In addition, I can set a manual time for the transition to occur. And the skylight should try and simulate that.

## Features of the Skylight:

- Connects to NTP for proper time
- Downloads the Time of Day
- Uses LEDs to simulate the sky
- Serves a web interface to control some features
- A knob controls brightness

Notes: And that, essentially, is the what the project is about. With a quick glance, you can see if it’s daytime, if it’s night, and get a feel for the time in a way that should feel very intuitive. And without a lot of complexity or set up.

## Technical Specifications

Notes: I would like to now discuss some of the technical details of the project, but does anybody have any questions so far?

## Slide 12

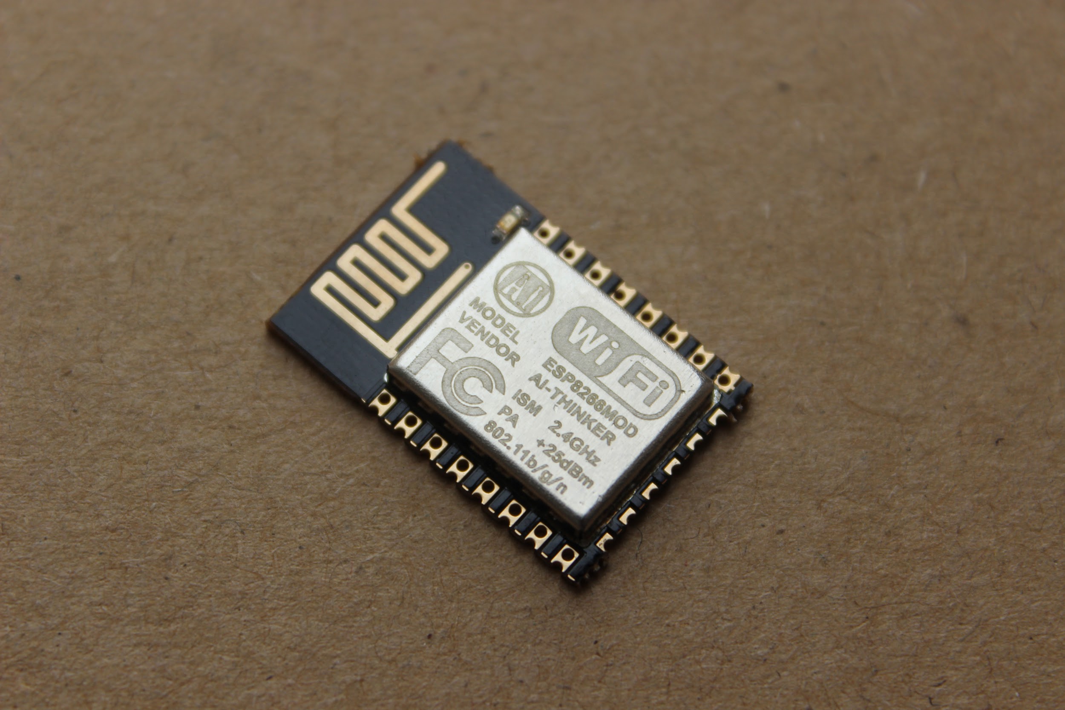
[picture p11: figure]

Hardware: MCU/WiFi Module https://hackaday.com/tag/esp-12/ for ideas

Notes: The main hardware component of the Skylight is a combination microcontroller/WiFi module called the ESP-12. This device is about the size of a postage stamp and costs around $3. But it can function as a web server, an access point, it can connect to wifi and do most things you could ask for. In addition, it can interface with GPIO, SPI, I2C and serial, and it can be programmed in LUA, Arduino, C and Micro-Python.

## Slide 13

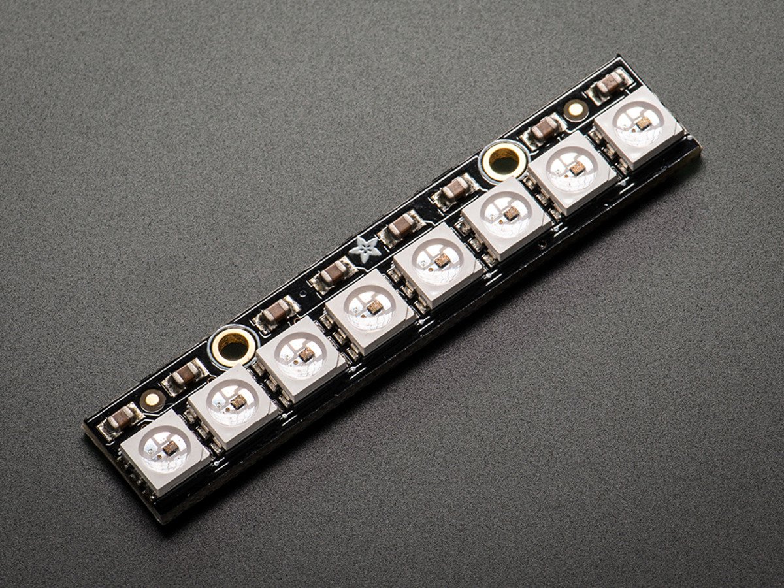
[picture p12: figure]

Hardware: Neopixels

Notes: In addition, I’m using an array of Neopixels for my ‘sky.’ These are addressable RGB leds that can provide a large range of colours and can be controlled independently with a one-wire interface.

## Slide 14

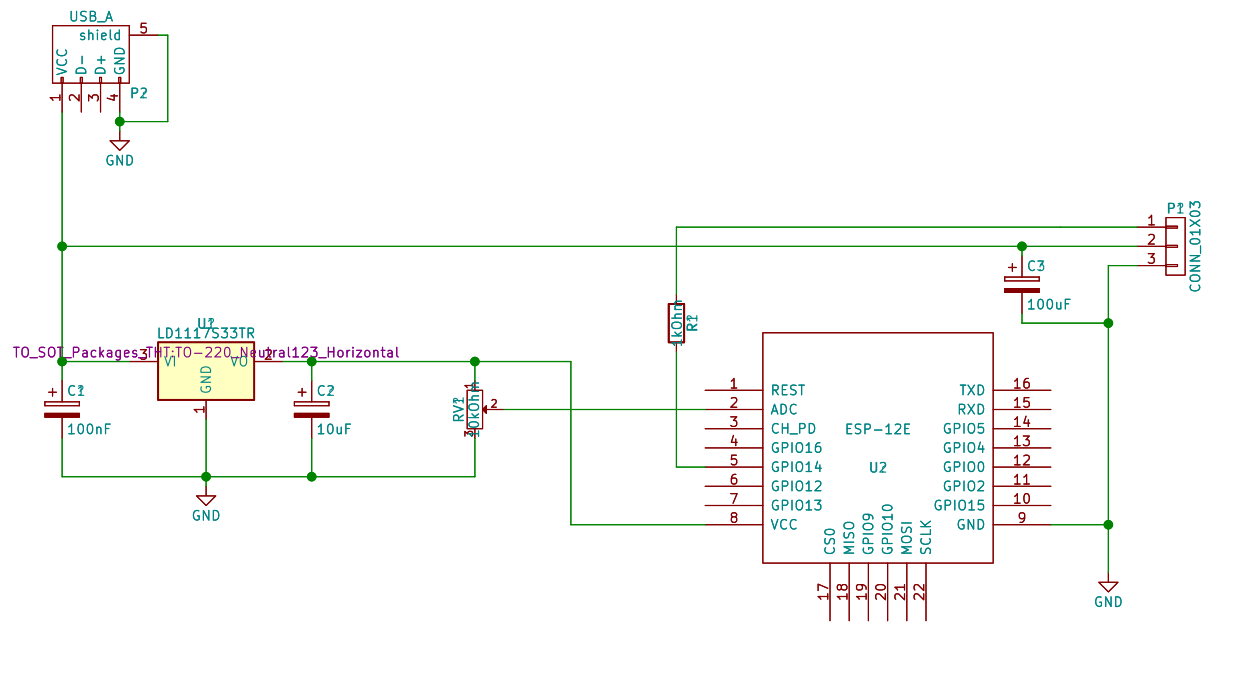
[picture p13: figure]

Hardware Schematic

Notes: The Skylight can run on about 500 mA, and so will be compatible with most microUSB adapters. I also had no problem running it off my laptop’s USB port. An LM1117 voltage regulator is used to drop the 5V input down to 3.3V for the ESP-12. Finally, the brightness knob is connected to the device via the ESP’s single ADC.

## Software:

- NTP used to Synchronise current time
- OpenWeatherMap API is used to get sunrise/sunset times for a current location.
- Programmed in Arduino with some additional libraries
- Example JSON response:
{"coord":{"lon":139,"lat":35}, "sys":{"country":"JP","sunrise":1369769524,"sunset":1369821049},
"weather":[{"id":804,"main":"clouds","description":"overcast clouds","icon":"04n"}],
"main":{"temp":289.5,"humidity":89,"pressure":1013,"temp_min":287.04,"temp_max":292.04},
"Wind":{"speed":7.31,"deg":187.002},"rain":{"3h":0},"clouds":{"all":92},"dt":1369824698,
"id":1851632,"name":"Shuzenji","cod":200}
*http://openweathermap.org/current

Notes: A large part of the project from a software perspective ended up trying to find a suitable API for getting the sunset/sunrise times. I finally ended up with OpenWeatherMap. With OpenWeatherMap, I could send a get request with the name of the city and country, and get sunrise and sunset times. And I also used a lot from the ESP8266 library for creating connections, setting up a small web and dns server, and creating the access point on first startup.

Questions?

## Viability of the Product:

- Fulfills the Product Requirements
- Cost of Materials was fairly low at $45, could be much lower.
- Few security / privacy concerns
- Lots of room for expansion

Pros

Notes: So I’d like to take a moment to talk about the viability of this product. In my opinion, the product is viable. It fulfills the requirements I had at the beginning of the project. It takes sunrise and sunset times and visually simulates them in a pleasing way. The cost of materials ended up being under fifty dollars, but it could be much much lower. I ended up purchasing a lot from Creatron, and I think the cost could easily be under $15. I’d also like to discuss security concerns, since they are rightly a very important issue for IoT devices. It was an intentional choice for me that the Skylight have little in the way of input. The Skylight uses GET requests, which are not secure, but the only thing communicated is your home city. The only sensitive information that the Skylight stores is your WiFi credentials, but you can only see the web interface if you’ve already connected to your home WiFi, so I believe that the Skylight is quite secure.

## Viability of the Product:

- Would require more development to be truly scalable
- Would require a professional license or a server for API calls.
- The enclosure is not what I had in mind.

Cons

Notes: However, there are some concerns if this were to become a commercial product. At the moment, the home location is hard-coded as well as the timezone. Implementing this dynamically was going to require yet another API and would also require some error handling to deal with many cities with the same name. I wasn’t willing to do this, so I left it hard-coded. In addition, Openweathermap places some restrictions on how their API is used. So if this were a commercial product, it would probably make sense to create your own server and have the Skylights send their requests there.

## Future Developments:

- Simulate some weather: cloudy, sunny, thunderstorms.
- Create themes: fireplace, aquarium.
- Repeatable alarms
- Change the temperature of the light: F.lux for your bedroom
- Implement Android/iOS apps
- Connect to MQTT for subtle notifications
- more..!

Feel free to suggest your own

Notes: In terms of future developments, I think there are a lot of ways you could expand on this functionality without even changing any of the hardware. Here are some of the ideas that I brainstormed:

## Project Skylight

A Smartlamp Providing Clarity

Eric Brauer
eric.m.brauer@gmail.com

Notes: I would be glad to take any questions you might have.

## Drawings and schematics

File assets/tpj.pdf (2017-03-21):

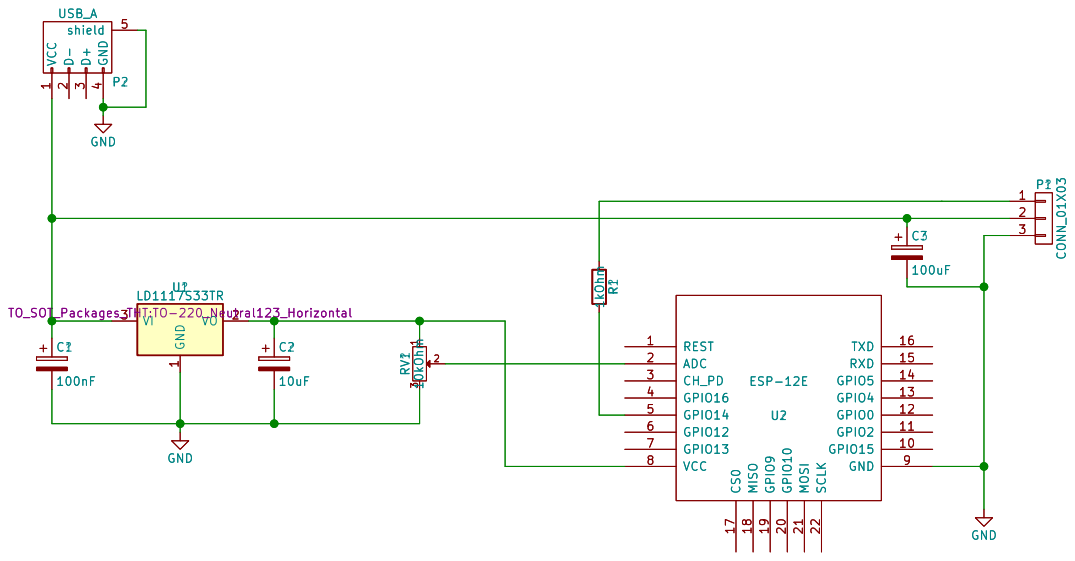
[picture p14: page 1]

Id: 1/1 Title: Project Skylight

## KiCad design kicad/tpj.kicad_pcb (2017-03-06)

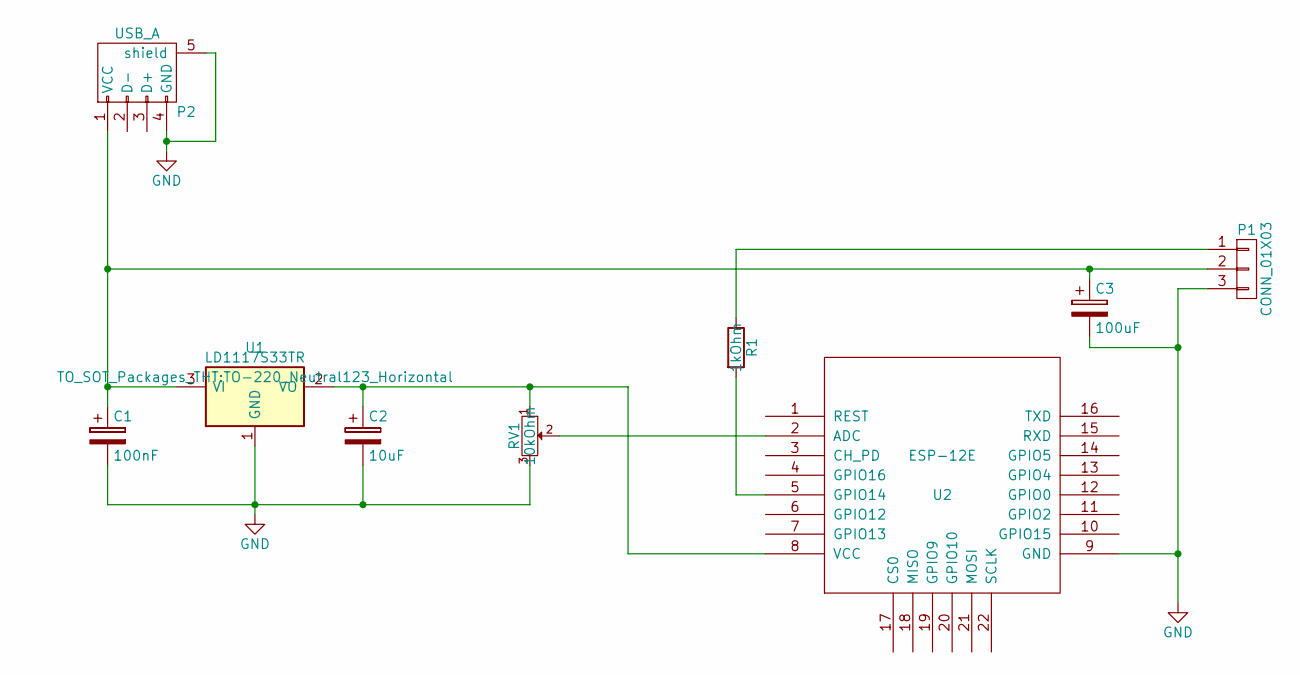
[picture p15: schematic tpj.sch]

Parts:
C1: 100nF; C_Axial_D5_L11_P18
C2: 10uF; C_Axial_D5_L11_P18
C3: 100uF; C_Axial_D5_L11_P18
P1: CONN_01X03; Pin_Header_Angled_1x03
P2: USB_A; USB_Micro-B
R1: 1kOhm; Resistor_Horizontal_RM7mm
RV1: 10kOhm; Potentiometer_WirePads_largePads
U1: LD1117S33TR; TO-220_Neutral123_Horizontal
U2: ESP-12E

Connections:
GND: C1.2, C2.2, C3.2, P1.3, P2.4 (GND), P2.5 (shield), RV1.3, U1.1 (GND), U2.9 (GND)
unnamed: C1.1, C3.1, P1.2, P2.1 (VCC), U1.3 (VI)
unnamed: C2.1, RV1.1, U1.2 (VO), U2.8 (VCC)
unnamed: P1.1, R1.1
unnamed: R1.2, U2.5 (GPIO14)
unnamed: RV1.2, U2.2 (ADC)

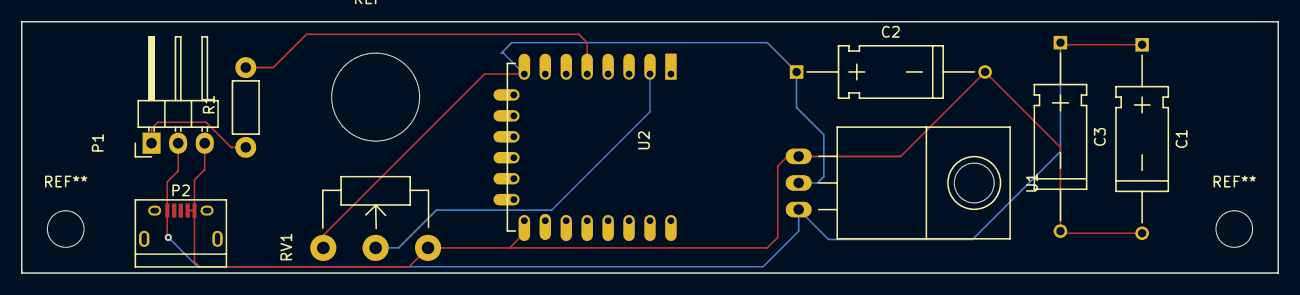
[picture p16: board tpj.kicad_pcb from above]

Board: 2 copper layers, 120.0 x 24.0 mm, 9 parts (0 on the bottom side), 6 nets.

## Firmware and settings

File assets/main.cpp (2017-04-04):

/*
-------------------------------------------------------------------------
    TITLE: Project Skylight
    AUTHOR: Eric Brauer
    DATE: 2017-04-04 (final version)

    DESCRIPTION: Project Skylight connects to a third-party API to collect
    dawn_time and dusk_time, and then simulates the current time of day using
    a Neopixel Array. Further detail will be explained in comments.
-------------------------------------------------------------------------
*/

/* The following are third-party libraries used by the project. I claim no
ownership / responsibility for their use. Anything in main.cpp was written by
me. NOTE: Links to the libraries can be found in the platformio.ini file. */
#include <NTPClient.h>          // used for setting time via NTP
#include "ESP8266WiFi.h"        // used for GET requests
#include <WiFiUdp.h>            // used for connection with NTPClient
#include <ArduinoJson.h>        // used to parse JSON response from API
#include <Adafruit_NeoPixel.h>  // used to control NeoPixels
#include <TimeLib.h>            // used for time-based functions
#include <ESP8266WebServer.h>   // used to serve web UI
#include <ESP8266mDNS.h>        // used to provide "skylight.local for web UI"
#include <WiFiManager.h>        // used for initial set up of WiFi credentials

#define PIN 14 // GPIO data pin used for NeoPixels
#define POT 0 // ADC pin used for brightness knob
#define TRANSITIONTIME 3600 //1 hour to get from night to day.  (in seconds)
#define THIRDOFTTIME TRANSITIONTIME / 3
#define TWOTHIRDSOFTIME THIRDOFTTIME * 2
enum {yellow, red, green}; // used for statusLight.
//states used for the STATE machine in loop()
enum {NOTIME, OLDTIMES, DAWNORDUSK, WAITFORDUSK, WAITFORDAWN, DUSK, DAWN};
unsigned char statusColor; //Initializing variables used with enums
unsigned char STATE;

/* The following variables are hard-coded, but in a commercial release would
need to be dynamic or otherwise set up properly. */

const int timezone_offset = -14400; // Eastern Daylight Timezone offset from UTC.
//const int timezone_offset = -18000; //Eastern Standard Timezone offset from UTC.

const char* tod_host = "api.openweathermap.org"; // url
const char* api_key = "ab33624b9ab307c2d056de2359eaedf5"; //api key
const char* my_city = "toronto"; // location
const char* my_country = "ca"; // country code

//String webPage = "";

/* The following are the main global variables that define the times when
TOD transitions occur. They are set in either getTODRequest() or in parseSunset
or parseSunrise when a manual alarm is set. they are used in the STATE machine.
time_t means that these are seconds since Epoch (Jan 1st, 1970), and in local time.
*/
volatile time_t dawn_time;
volatile time_t dusk_time;

// function delarations follow
void colorWipe(uint32_t c, uint8_t wait);
void skySim(uint32_t outer, uint32_t inner);
void skyTransition(int wait);
void skyState1(unsigned char i);
void skyState2(unsigned char i);
void skyState3(unsigned char i);
void statusLight(unsigned char statusColor);
void handleUserInputError();
void handleSubmit();
void handleDemo();
void handleAck();
void parseSunrise(int hour, int minute);
void parseSunset(int hour, int minute);
void changeBrightness();
short int calculateStateOut(int x);
void getTODRequest();

//Initializing objects
WiFiUDP ntpUDP;
WiFiClient client;

ESP8266WebServer server(80); // 80 = port for http
MDNSResponder mdns;

// Parameter 1 = number of pixels in strip
// Parameter 2 = Arduino pin number (most are valid)
// Parameter 3 = pixel type flags, add together as needed:
//   NEO_KHZ800  800 KHz bitstream (most NeoPixel products w/WS2812 LEDs)
Adafruit_NeoPixel strip = Adafruit_NeoPixel(16, PIN, NEO_GRB + NEO_KHZ800);

// You can specify the time server pool and the offset (in seconds, can be
// changed later with setTimeOffset() ). Additionaly you can specify the
// update interval (in milliseconds, can be changed using setUpdateInterval() ).
NTPClient timeClient(ntpUDP, "ca.pool.ntp.org", timezone_offset, 60000);


void handleRoot() { //this creates HTML code for the main webPage.
    String webPage = "";
    webPage += "<h1>Skylight</h1>";
    webPage += "<p>Time is now: ";
    webPage += timeClient.getFormattedTime();
    webPage += "</p><h3>Set Sunrise:</h3>";
    webPage += "<form action='submit' method='POST'>";
    webPage += "<p>Hour: <input type='text' name='rise_hour' maxlength='2' style='width:50px;'>";
    webPage += "Minute:  <input type='text' name='rise_min' maxlength='2' style='width:50px;'>";
    webPage += "AM  <input type='submit' value='Save'></form> ";
    webPage += "<h3>Set Sunset:</h3> ";
    webPage += "<form action='submit' method='POST'>";
    webPage += "<p>Hour: <input type='text' name='set_hour' maxlength='2' style='width:50px;'>";
    webPage += "Minute:  <input type='text' name='set_min' maxlength='2' style='width:50px;'>";
    webPage += "PM  <input type='submit' value='Save'></form>";
    webPage += "<p><a href='demo'><button style='width:100%;'>Run a Demo</button></a>&nbsp;</p>";
    webPage += "<p><a href='reset'><button style='width:100%;'>Reset Manual Alarms</button></a>&nbsp;</p>";
    server.send(200, "text/html", webPage);
}

void handleSubmit() { // when changes are submitted, this parses the user input.
    char sunset_flag = 0;
    int x;
    int hour = 0;
    int minute = 0;
    if (server.args() > 0 ) { // if user input exists,
        for ( uint8_t i = 0; i < server.args(); i++ ) { // for each argument,
            Serial.println(server.argName(i));
            Serial.println(server.arg(i));
            x = server.arg(i).toInt(); // convert to an integer
            if (server.argName(i) == "rise_hour") { // if it's a sunrise time,
                if ((x > 12) || (x < 1)) { // check if it's out of bounds
                    handleUserInputError();
                    return;
                }
                else {
                    hour = x; //set hour to the user input.
                }
            }
            if (server.argName(i) == "set_hour") { // if it's a sunset time,
                if ((x > 12) || (x < 1)) { // check if out of bounds.
                    handleUserInputError();
                    return;
                }
                else {
                    hour = x; //set hour to user input, and raise sunset flag.
                    sunset_flag = 1;
                }
            }
            if ((server.argName(i) == "rise_min") || (server.argName(i) == "set_min")) { //if it's minutes,
                if ((x > 59) || (x < 0)) { //check if out of bounds
                    handleUserInputError();
                    return;
                }
                else {
                    minute = x;
                }
            }
        }
    }
    if (sunset_flag) { //if sunset flag raised, handle the input as sunset.
        parseSunset(hour, minute);
    }
    else
        parseSunrise(hour, minute); //else, sunrise.
    handleAck(); //send a response to user.
}

void parseSunrise(int hour, int minute) { //sets dawn_time from use input.
    time_t time_temp;
    TimeElements tm;
    breakTime(now(), tm); // get year, month, day for today.
    // comment this out for presentation
    // tm.Day += 1;
    tm.Hour = hour; // manually set hour to user input
    tm.Minute = minute; // manually set minute to user input
    tm.Second = 0; // set seconds to zero
    time_temp = makeTime(tm); // set a new time with same date.
    Serial.print("dawn time set to: ");
    Serial.println(time_temp);
    dawn_time = time_temp; // set dawn_time
    STATE = DAWNORDUSK; // change STATE to handle new info
}

void parseSunset(int hour, int minute) { //set dusk_time from user input
    TimeElements tm;
    time_t time_temp;
    breakTime(now(), tm);
    tm.Hour = hour+12; // add 12 to make it a PM time.
    tm.Minute = minute;
    tm.Second = 0;
    time_temp = makeTime(tm);
    Serial.print("dusk time set to: ");
    Serial.println(time_temp);
    dusk_time = time_temp;
    STATE = DAWNORDUSK;

}

void handleAck() { //sends a acknowledgement message.
    String message = "";
    message += "<p><b>Alarm has been set.</b></p>";
    message += "<p>Press OK to return to previous page.</p>&nbsp;";
    message += "<a href='/'><button>OK</button></a>";
    server.send(200, "text/html", message);
}


void handleRst() { //sends a reset message
    String message = "";
    getTODRequest(); // this overwrites user dusk and dawn_time with values from web.
    STATE = DAWNORDUSK;
    message += "<p><b>Alarms have been forgotten. Using actual dawn/dusk.</b></p>";
    message += "<p>Press OK to return to previous page.</p>&nbsp;";
    message += "<a href='/'><button>OK</button></a>";
    server.send(200, "text/html", message);
}

void handleUserInputError() { //sends an error message if user input is invalid.
    String message = "";
    message += "<p><b>Error: Please enter a valid time.</b></p>";
    message += "<p>Press OK to return to previous page.</p>&nbsp;";
    message += "<a href='/'><button>OK</button></a>";
    server.send(200, "text/html", message);
}

void handleDemo() { //runs a demo.
    String message = "";
    message += "<p><b>Running demo...</b></p>";
    message += "<p>Press OK to return to previous page.</p>&nbsp;";
    message += "<a href='/'><button>OK</button></a>";
    server.send(200, "text/html", message);
    skyTransition(10); // runs a neopixel transition with 10 ms between states.
}

void handleNotFound(){ // recommended from libary. Handles a bad page request.
    String message = "File Not Found\n\n";
    message += "URI: ";
    message += server.uri();
    message += "\nMethod: ";
    message += (server.method() == HTTP_GET)?"GET":"POST";
    message += "\nArguments: ";
    message += server.args();
    message += "\n";
    for (uint8_t i=0; i<server.args(); i++){
        message += " " + server.argName(i) + ": " + server.arg(i) + "\n";
    }
    server.send(404, "text/plain", message);
}

void setup() {
    Serial.begin(9600);

    /* wifiManager tries to connect to a remembered wifi access point. If it
    fails, then will set the ESP-12 to station mode, where it provides its own
    access point with SSID "DIGITAL SKYLIGHT." The use can then scan available
    access points and enter credentials. statusLight() blinks one of the
    neopixels with the colour to indicate status. */
    WiFiManager wifiManager;
    wifiManager.autoConnect("DIGITAL SKYLIGHT");
    if (wifiManager.autoConnect())
        statusLight(green);
    else
        statusLight(yellow);

    timeClient.begin();

    strip.begin();
    strip.show(); // Initialize all pixels to 'off'

    //starts up micro-DNS server. The Skylight will be reachable at skylight.local.
    if (mdns.begin("skylight", WiFi.localIP())) {
    Serial.println("MDNS responder started");
    }

    /* sets the behaviour of the web server. each of these indicates a suffix after
    skylight.local. So skylight.local/ is where we find the main UI, and so on. */
    server.on("/", handleRoot);
    server.on("/submit", handleSubmit);
    server.on("/demo", handleDemo);
    server.on("/reset", handleRst);
    server.onNotFound(handleNotFound);
    server.begin();
    Serial.println("HTTP server started");

    //IP to use if DNS server fails. Used for debugging.
    Serial.print("IP address: ");
    Serial.println(WiFi.localIP());

    //attachInterrupt(POT, changeBrightness, CHANGE);
    //set initial state for loop().
    STATE = NOTIME;
}

void checkNTPServer() { // requests sync with NTP.
    timeClient.update();
    Serial.println(timeClient.getFormattedTime()); //debugging
    setTime(timeClient.getEpochTime()); //debugging
}

void getTODRequest() { // sends a GET request to get TOD, parses response, sets times
    time_t time_temp;
    String line;
    const int httpPort = 80;

    // stop if connection fails
    if (!client.connect(tod_host, httpPort)) {
        Serial.println("connection failed");
        return;
    }

    // generate the get request
    String url = "/data/2.5/weather?q=";
    url += my_city;
    url += ",";
    url += my_country;
    url += "&APPID=";
    url += api_key;

    Serial.print("Requesting URL: ");
    Serial.println(url);

    // This will send the request to the server
    client.print(String("GET ") + url + " HTTP/1.1\r\n" +
                 "Host: " + tod_host + "\r\n" +
                 "Connection: close\r\n\r\n");
    unsigned long timeout = millis();
    while (client.available() == 0) {
        if (millis() - timeout > 5000) {
            Serial.println(">>> Client Timeout !");
            statusLight(red); // indicate failure with red status light.
            client.stop();
            return;
        }
    }

    // Read Response, ignore HTTP headers
    Serial.println("request sent");
    while (client.connected()) {
        String line = client.readStringUntil('\n');
        if (line == "\r") {
            Serial.println("headers received");
            break;
        }
    }

    line = client.readStringUntil('\n');
    // variable line stores the actual JSON response that we wish to parse.
    Serial.print(line);

    // Initialize object to parse JSON. stop if failure.
    DynamicJsonBuffer jsonBuffer;
    JsonObject &root = jsonBuffer.parseObject(line);
    if (!root.success()) {
      Serial.println("parseObject() failed");
      return;
    }

    /* the times sent from openweathermap are in epoch times at UTC.
    So, to deal with them, we add the timezone_offset and check that they aren't
    too far in the future. Otherwise we might overwrite an upcoming event with
    an event happening tomorrow. */
    time_temp = root["sys"]["sunrise"];
    if ((time_temp + timezone_offset) <= (now() + 43200)) //only save if in the next 12 hours
        dawn_time = time_temp + timezone_offset; //dawn_time is an epoch in local timezone.
    time_temp = root["sys"]["sunset"];
    if ((time_temp + timezone_offset) <= (now() + 43200))
        dusk_time = time_temp + timezone_offset;
    Serial.println("dawn time: ");
    Serial.println(dawn_time);
    Serial.println("dusk time: ");
    Serial.println(dusk_time);

    Serial.println("closing connection");
}

void loop() {
    server.handleClient(); // if user requests a webPage, handle the request.
    changeBrightness(); // if ADC value changes, set a different brightness
    Serial.println(timeClient.getFormattedTime());
    /* Here is the main state machine. Used to set up transitions between events.*/
    switch (STATE) {
        case NOTIME: //initial state. No time set on power up, sync with NTP.
            checkNTPServer();

            if (!timeNotSet) // if time is set successfully, move to next state.
                STATE = DAWNORDUSK;
        break;

        case OLDTIMES: // if times are too old, run a TOD request to update them.
            getTODRequest();
            STATE = DAWNORDUSK;
        break;

        case DAWNORDUSK: // try to determine what is the next transition event.
            Serial.println(STATE);
            Serial.print("dusk time: "); //debugging messages.
            Serial.print(dusk_time);
            Serial.print("\n");
            Serial.print("now: ");
            Serial.print(now());
            Serial.print("\n");
            Serial.print("dawn time: ");
            Serial.print(dawn_time);
            Serial.print("\n");
            Serial.println(now() >= dawn_time);
            Serial.println(now() < dusk_time);
            if ((now() >= dawn_time) && (now() < dusk_time)) {
                Serial.println("It is daytime. Waiting for dusk.");
                STATE = WAITFORDUSK;
            }
            else if (now() < dawn_time) {
                Serial.println("It is nighttime. Waiting for dawn.");
                STATE = WAITFORDAWN;
            }
            // if dawn_time and dusk_time are both older than now, we need an update.
            if ((now() > dawn_time) && (now() > dusk_time))
                STATE = OLDTIMES;
        break;

        case WAITFORDUSK: // set Neopixels to daylight. Wait.
            Serial.println(STATE);
            Serial.print("Time until dusk: ");
            Serial.print(dusk_time - now());
            Serial.print("\n");
            // we will begin a transition about 40 minutes before a scheduled event.
            if ((dusk_time - now()) <= TWOTHIRDSOFTIME)
                STATE = DUSK;
            else {
                skyState3(255);
                delay(100);
            }
        break;

        case WAITFORDAWN: // set Neopixels to off. Wait.
            Serial.println(STATE);
            Serial.print("Time until dawn: ");
            Serial.print(dawn_time - now());
            Serial.print("\n");
            // we will begin a transition about 40 minutes before a scheduled event.
            if ((dawn_time - now()) <= TWOTHIRDSOFTIME)
                STATE = DAWN;
            else {
                skyState1(0);
                delay(1000);
            }
        break;

        case DUSK: //run the transition
            Serial.println(dusk_time - now());
            // if we're twenty minutes past dusk, the event is over. go back to waiting.
            if ((dusk_time + THIRDOFTTIME) < now())
                STATE = DAWNORDUSK;
            /* if not, the show is still on. we need to translate a time duration
            into 3 sets chars. Each transition has 255 possible states.
            calculateStateOut will translate time into a state. Since this is
            dusk, everything is happening in reverse, and so we subtract this result
            from 765 (255 * 3). */
            else {
                /* we use the time remaining before dusk to calculate the state
                that we want our neopixels to be in. */
                short int yy = (calculateStateOut(dusk_time - now()));
                Serial.println(yy);
                short int y = 765 - yy;
                Serial.println(y);
                // skyStates are the Neopixel functions.
                if (y <= 255)
                    skyState1(y);
                else if (y > 510)
                    skyState3(y-510);
                else
                    skyState2(y-255);
            }
        break;
        case DAWN: // dawn occurs in the same way as dusk, but not reversed.
            if ((dawn_time + THIRDOFTTIME) < now())
                STATE = DAWNORDUSK;
            else {
                short int y = calculateStateOut(dawn_time - now());
                if (y <= 255)
                    skyState1(y);
                else if (y > 510)
                    skyState3(y-510);
                else
                    skyState2(y-255);
            }
        break;

    }

}

short int calculateStateOut(int x) { // returns an integer from a time remaining
    return ((x - 2400) / (-TRANSITIONTIME / 765));
}

void statusLight(unsigned char statusColor) { // blinks a status light
    uint32_t x;
    switch (statusColor) {
        case yellow:
            x = strip.Color(255, 255, 0);
            break;
        case red:
            x = strip.Color(255, 255, 0);
            break;
        case green:
            x = strip.Color(0, 255, 0);
            break;
    }
    for (int i = 0; i < 2; i++) {
        strip.setPixelColor(0, x);
        strip.show();
        delay(250);
        strip.setPixelColor(0, strip.Color(0,0,0));
        strip.show();
        delay(250);
    }
}

void changeBrightness() { // changes brightness level if there's a change on ADC
    static char previous_state;
    if ((analogRead(POT)>>4) != previous_state) {
        strip.setBrightness((analogRead(POT)>>4));
        strip.show();
        previous_state = (analogRead(POT)>>4);
    }
}

void skyTransition(int wait) { // used for demo. Cycles through all the skyStates.
    for (int i =0; i < 255; i++) {
        skyState1(i);
        delay(wait);
    }
    for (int i=0; i < 255; i++) {
        skyState2(i);
        delay(wait);
    }
    for (int i=0; i < 255; i++) {
        skyState3(i);
        delay(wait);
    }
}

/* The following are functions written to control the neopixels. Some explanation
is probably necessary: The NeoPixel libary sets Pixel colour using a strip.Color()
data type. There are three 8-bit numbers here, and they correspond to a level of
colour between 0 and 255 for Red Green Blue. So Strip.Color(255, 0, 0) sets Red
to maximum, and other colours off. Strip.Color(255, 255, 255) is a pure white */

//first state. No lights to a pre-dawn state.
void skyState1(unsigned char i) { // outer lights set to 50% blue, inner lights set to 50% red, 100% blue.
    Serial.print("SkyState 1, state: ");
    Serial.println(i);
    skySim(strip.Color(0, 0, (i/2)), strip.Color((i/2), 0, i));
}

//second state. Pre-dawn to dawn.
void skyState2(unsigned char i) { //outer lights from 50% blue to 50% red and 100% blue.
    //inner lights from 50% red, 100% blue to Yellow.
    Serial.print("SkyState 2, state: ");
    Serial.println(i);
    skySim(strip.Color((i/2), 0, (127+(i/2))), strip.Color((127+(i/2)), i, (255-i)));
}

//third state. Dawn to Day.
void skyState3(unsigned char i) { //outer from magenta to cyan. Inner from yellow to white.
    Serial.print("SkyState 3, state: ");
    Serial.println(i);
    skySim(strip.Color((127-(i/2)), i, 255), strip.Color(255, 255, i));
}

void skySim(uint32_t outer, uint32_t inner) { //divides the array into threes, sets the lights.
    uint8_t x = strip.numPixels() / 3;
    for (uint8_t i=0; i<strip.numPixels(); i++) {
        if ((i > x) && (i < (strip.numPixels() - x - 1))) //if the pixel address is in the middle, set it to inner colour.
            strip.setPixelColor(i, inner);
        else
            strip.setPixelColor(i, outer); // else, set it to outer colour.
    }
    changeBrightness(); //change the brightness based on ADC reading.
    strip.show(); // Output the new state to the Neopixels.
}

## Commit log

2017-02-02 some fixes, parsing needs escaped quotes??
    [main.cpp]
2017-02-15 fixed json parsing issue
    [main.cpp]
2017-03-05 added kicad files
    [tpj.kicad_pcb, tpj.sch]
2017-03-17 added schematic
    [tpj.sch]
2017-03-19 fixes to server handling of post arguments
    [main.cpp]
2017-03-19 fixes to response handling so far
    [main.cpp]
2017-03-19 corrected for daylight savings time
    [main.cpp]
2017-04-03 fixed the manual alarms
    [main.cpp]
2017-04-04 fixed merge conflict. adding comments
    [main.cpp]
2017-04-04 including assets folder with presentation, documents, datasheets, schematic
